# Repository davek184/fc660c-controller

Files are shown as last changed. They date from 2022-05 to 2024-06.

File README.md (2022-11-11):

# FC660C Controller with USB-C

This revision was designed to maximize RGB underglow in the Norbauer Heavy-6 polycarb case.  To that end the reset button has been moved and is not accessible when installed in the case.  

RGB underglow lights can be added via a JST connector. Rooski15 has a great how to guide [here](https://www.keebtalk.com/t/adding-rgb-to-fc660c-with-hasu-controller/14484)

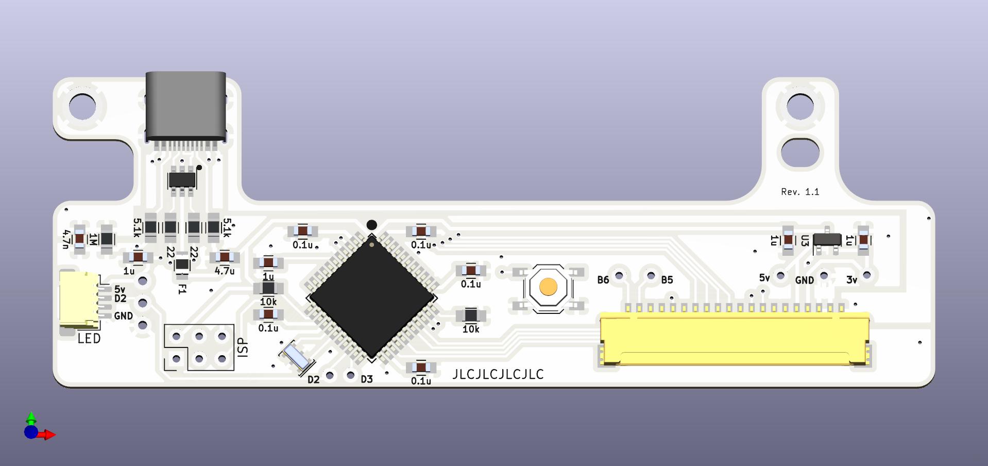
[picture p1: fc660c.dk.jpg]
FC660CFront

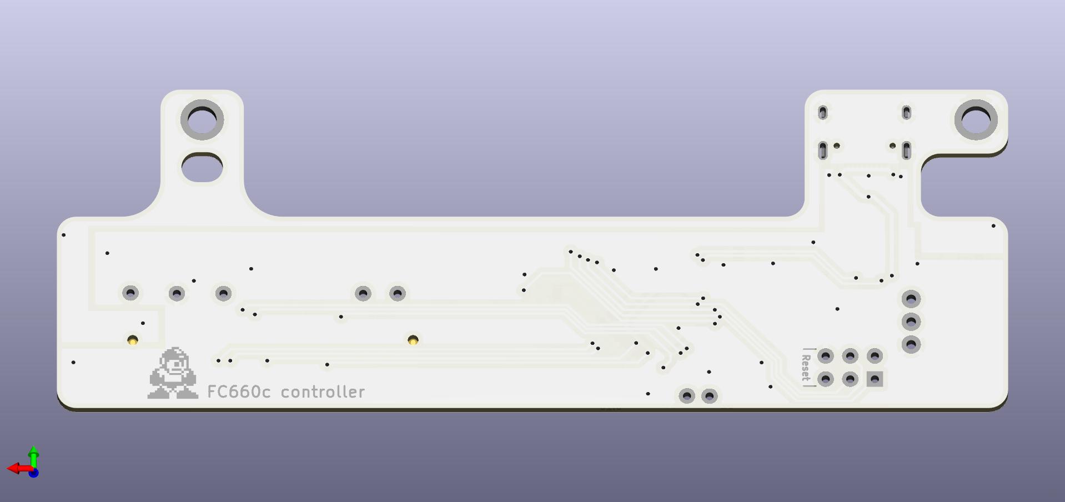
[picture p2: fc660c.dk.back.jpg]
FC660CBack



## Features
- Fully compatible with keymaps for Hasu's FC660C controller
- USB-C port (required small case modification)
- ESD protection circuit

## Bill of materials (BOM)
Please have a look at the manufacuring files!

_Ignore Rev1.0 it had problems with the LED connector.  Leaving in the Repo incase someone needs to refer back to them._

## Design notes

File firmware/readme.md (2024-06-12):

# Firmware

Firmware Update - June 2024

A few people reported their insert LED was always on.  The firmware files below resolve that; pick the version you would like:

- [Insert LED off](davek184_fc660c_vial_BgRgb44LEDs_InsertLED_Off.hex) *(there is NO insert LED and/or you always want it off; most people)*
- [Insert LED Num Lock](davek184_fc660c_vial_BgRgb44LEDs_InsertLED_NumLock.hex)
- [Insert LED Scroll Lock](davek184_fc660c_vial_BgRgb44LEDs_InsertLED_ScrollLock.hex)

New firmware has boot magic to enter boot loader mode **hold down Esc while powering on** (this doesn't apply to the old firmware so you may need to hit the reset button on the controller)

*(Alternately, compile your own firmware. Desired source files are included in the repo)*

Note: If you don not use RBG underglow official VIA firmware can be used [FC660C](https://www.caniusevia.com/docs/download_firmware)

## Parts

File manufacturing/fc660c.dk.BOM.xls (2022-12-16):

FC660C Controller BOM
Manufacturer | Manufacturer Part Number | LCSC | Designator | Qty | Description
Samsung Electro-Mechanics | CL21B104KBCNNNC | C1711 | C1-C5 | 5 | 100nf capacitor
Samsung Electro-Mechanics | CL21A475KAQNNNE | C1779 | C6 | 1 | 4.7uf capacitor
Samsung Electro-Mechanics | CL21A105KBCLNNC | C318694 | C7, C9, C10, C11 | 4 | 1uf capacitor
Samsung Electro-Mechanics | CL21B472KCANNNC | C21217 | C8 | 1 | 4.7nF capacitor
Walsin Tech Corp | WR08X103JTL | C163957 | R3, R4 | 2 | 10k ohm resistor
Walsin Tech Corp | WR08X220JTL | C168490 | R1, R2 | 2 | 22 ohm resistor
Walsin Tech Corp | WR08X512JTL | C164004 | R5, R6 | 2 | 5.1k ohm resistor
Walsin Tech Corp | WR08X105JTL | C163969 | R7 | 1 | 1M ohm resistor
Microchip Tech | ATMEGA32U4-AU | C44854 | U1 | 1 | Microcontroller
STMicroelectronics | USBLC6-2SC6 | C7519 | U2 | 1 | Diode ESD
Murata Electronics | CSTNE16M0V530000R0 | C341521 | X1 | 1 | Resonator
TLC Electronic | TLC-PSMD050 | C261942 | F1 | 1 | PTC Fuse
Korean Hroparts Elec | TYPE-C-31-M-12 | C165948 | J1 | 1 | USB-C Connector
Hirose | DF14-20P-1.25H(56) | C506679 | J3 | 1 | Board to board connector
Korean Hroparts Elec | K2-1187SQ-A4SW-06 | C92584 | SW1 | 1 | Tactile switch
JST Sales America | SM04B-SRSS-TB(LF)(SN) | C160404 | J2 | 1 | JST Connector
Youtai Semiconductor Co., Ltd. | XC6206P332MR | C347376 | U3 | 1 | Linear Voltage Regulator 3.3V

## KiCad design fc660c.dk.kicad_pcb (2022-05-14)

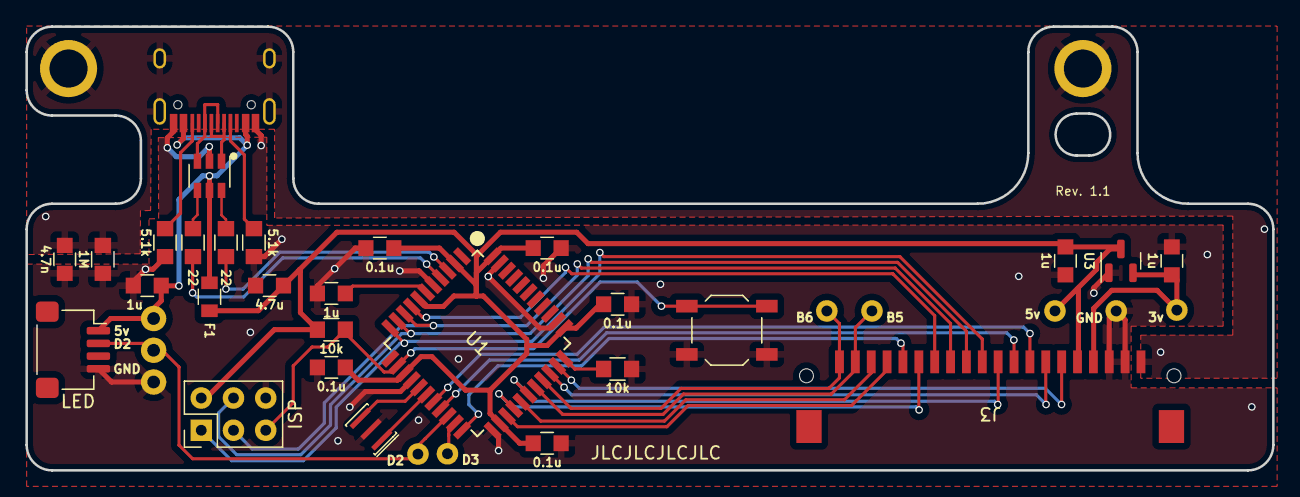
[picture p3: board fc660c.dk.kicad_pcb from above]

Board: 2 copper layers, 98.2 x 35.0 mm, 31 parts (0 on the bottom side), 33 nets.

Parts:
C1, C2, C3, C4, C5: 0.1u; C_0805
C6: 4.7u; C_0805
C7, C9, C10, C11: 1u; C_0805
C8: 4.7n; C_0805
F1: Polyfuse_Small; F_0805
J1: HRO-TYPE-C-31-M-12
J2: ai03_ud; JST_SH_SM04B-SRSS-TB_1x04-1MP_P1.00mm_Horizontal
J2#2: ISP; isp_standard
J3: DF14-20P-1.25H
J4: Solder header; solder_header
R1, R2: 22; R_0805
R3, R4: 10k; R_0805
R5, R6: 5.1k; R_0805
R7: 1M; R_0805
S1, S2: SCREW; screw
SW1: SW_PUSH; SW_SPST_TL3342
U1: ATmega32U4; ATMEGA32U4
U2: USBLC6-2SC6
U3: XC6206P332MR; SOT-23
X1: 16mhz; Resonator_SMD_muRata_CSTNExxV-3Pin-p1.2

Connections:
+3V3: C10.1, J3.4, U3.2 (VO)
D+: R1.1, U2.4 (I/O2)
D-: R2.1, U2.6 (I/O1)
Earth: C8.1, J1.13 (SHIELD), J3.1, R7.2, S1.1, S2.1
GND: C1.2, C2.2, C3.2, C4.2, C5.2, C6.2, C7.2, C8.2, C9.1, C10.2, C11.2, J1.1 (GND), J1.12 (GND), J2.4, J2#2.6, J3.2, J3.3, J4.3, R4.2, R5.2, R6.2, R7.1, SW1.1, U1.5 (UGND), U1.15 (GND), U1.23 (GND), U1.35 (GND), U1.43 (GND), U2.2 (GND), U3.1 (GND), X1.3
MISO: J2#2.1, J3.11, U1.11 ((PDO/MISO/PCINT3)PB3)
MOSI: J2#2.4, J3.12, U1.10 ((PDI/MOSI/PCINT2)PB2)
unnamed: C7.1, U1.6 (UCAP)
unnamed: J1.4 (CC1), R5.1
unnamed: J1.5 (DN2), J1.7 (DN1), U2.1 (I/O1)
unnamed: J1.6 (DP1), J1.8 (DP2), U2.3 (I/O2)
unnamed: J1.10 (CC2), R6.1
unnamed: R1.2, U1.4 (D+)
unnamed: R2.2, U1.3 (D-)
unnamed: R4.1, U1.33 ((~HWB~)PE2)
unnamed: U1.16 (XTAL2), X1.2
unnamed: U1.17 (XTAL1), X1.1
P1: J3.20, U1.30 ((ADC13/OC1B/OC4B/PCINT13)PB6)
P2: J3.19, U1.29 ((ADC12/OC1A/~OC4B~/PCINT12)PB5)
P3: J3.18, U1.27 ((T0/OC4D/ADC10)PD7)
P4: J3.17, U1.25 ((ICP2/ADC8)PD4)
P5: J3.16, U1.22 ((XCK1/~CTS~)PD5)
P6: J3.15, U1.26 ((T1/~OC4D~/ADC9)PD6)
P7: J3.14, U1.8 ((SS/PCINT0)PB0)
P8: J2#2.3, J3.13, U1.9 ((SCLK/PCINT1)PB1)
P11: J3.10, U1.28 ((ADC11/PCINT4)PB4)
P12: J3.9, U1.19 ((SDA/INT1)PD1)
P13: J3.8, U1.18 ((OC0B/SCL/INT0)PD0)
P14: J3.7, U1.31 ((OC3A/~OC4A~)PC6)
P15: J3.6, U1.32 ((ICP3/CLK0/OC4A)PC7)
RST: J2#2.5, R3.2, SW1.2, U1.13 (RESET)
VBUS: C11.1, F1.2, J1.2 (VBUS), J1.11 (VBUS), J2.1, J4.1, U2.5 (VBUS)
VCC: C1.1, C2.1, C3.1, C4.1, C5.1, C6.1, C9.2, F1.1, J2#2.2, J3.5, R3.1, U1.2 (UVCC), U1.7 (VBUS), U1.14 (VCC), U1.24 (AVCC), U1.34 (VCC), U1.44 (AVCC), U3.3 (VI)

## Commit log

2022-05-14 Rev 1.1
    [fc660c.dk.BOM.xls, fc660c.dk.kicad_pcb, fc660c.dk.kicad_sch]
2022-05-14 Adding old revision for archiving
    Don't use rev 1.0 there were problems with the LED data line and a few other minor problems.
2022-05-14 BOM Part Number Correction
    [fc660c.dk.BOM.xls]
2022-05-14 Sample Firmware
    Recommend compiling your own firmware with the appropriate number of LEDS.
2022-06-23 Adding JLC Manufacturing files
    June 2022 A set of PCBs with parts assembly has been made from these files
    [fc660c.dk.JLC.BOM.csv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]
2022-12-16 Delete fc660c.dk.BOM.xls
    Removing as the other manufacturing files are generate from the PCB and more reliable
    [fc660c.dk.BOM.xls]
2022-12-16 Small Adjustments
    Corrected RGB Designator to be J4 (set ISP header J2 to not export to BOM/Place files)
    [fc660c.dk.BOM.xls]
2024-06-05 Firmware Updates
    A few people reported the Insert LED was always on using this controller. Precompiled VIAL firmware with a few different Insert LED functions and the latest from VIAL.
2024-06-05 Firmware Updated 2
    Added Boot magic hold down esc when plugging in to enter boot load mode
